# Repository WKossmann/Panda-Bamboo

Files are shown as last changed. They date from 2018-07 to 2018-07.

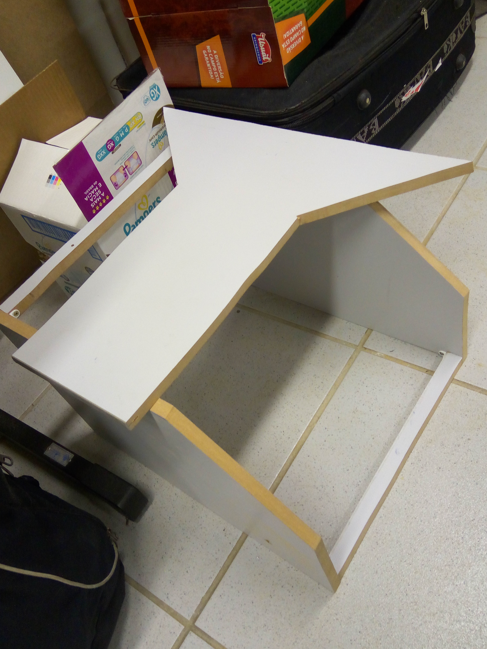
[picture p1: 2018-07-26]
IMG_20170504_185952.jpg

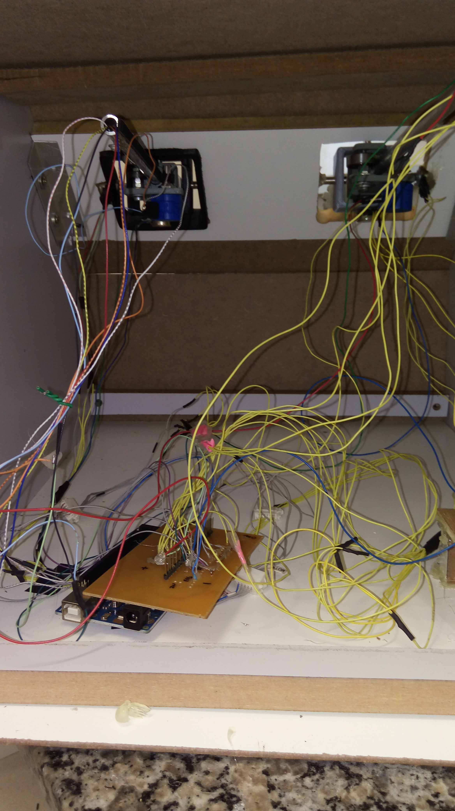
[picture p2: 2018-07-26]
20170629_162037.jpg

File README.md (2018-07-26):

# Panda-Bamboo
Projeto de um simulador de cirurgia laparoscópica, desenvolvido para a disciplina de Projeto Integrado do curso de Engenharia Mecatrônica da UFRN.
## Autores
- ANDRES ANTONIO ALVARADO ROJAS
- ELITELMA DA SILVA SOUZA DE ARAÚJO
- JOÃO BEZERRA DA ROCHA NETO
- TIAGO HÉRIQUE SILVA DE ALMEIDA
- URURAÍ DE CAMPOS GUIMARÃES FILHO
- WENDELL ALVES DA SILVA
- WILLIAN KOSSMANN DA SILVA

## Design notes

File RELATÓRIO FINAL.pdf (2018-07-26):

UNIVERSIDADE FEDERAL DO RIO GRANDE DO NORTE CENTRO DE TECNOLOGIA
MCA0004 - PROJETO INTEGRADO DE MECATRÔNICA

Docentes:
ADELARDO ADELINO DANTAS DE MEDEIROS PABLO JAVIER ALSINA
SAMAHERNI MORAIS DIAS
MARCIO VALERIO DE ARAUJO

SIMULADOR DE CIRURGIA LAPAROSCÓPICA DE BAIXO CUSTO

Discentes:
ANDRES ANTONIO ALVARADO ROJAS ELITELMA DA SILVA SOUZA DE ARAÚJO JOÃO BEZERRA DA ROCHA NETO TIAGO HÉRIQUE SILVA DE ALMEIDA URURAÍ DE CAMPOS GUIMARÃES FILHO WENDELL ALVES DA SILVA
WILLIAN KOSSMANN DA SILVA

Natal-RN

2017

ANDRES ANTONIO ALVARADO ROJAS: 20160153730

ELITELMA DA SILVA SOUZA DE ARAÚJO: 20160153777

JOÃO BEZERRA DA ROCHA NETO: 20160153937

TIAGO HÉRIQUE SILVA DE ALMEIDA: 20160154030

URURAÍ DE CAMPOS GUIMARÃES FILHO: 20160154040

WENDELL ALVES DA SILVA: 20160154059

WILLIAN KOSSMANN DA SILVA: 20160154068

### SIMULADOR DE CIRURGIA LAPAROSCÓPICA DE BAIXO CUSTO

Relatório Final apresentado à disciplina de Projeto
Integrado | de | Mecatrônica, | correspondente | à
avaliação da 3ª unidade do semestre 2017.1 do curso de Engenharia Mecatrônica da Universidade Federal do Rio Grande do Norte, sob orientação dos Professores Adelardo Adelino Dantas de Medeiros, Pablo Javier Alsina, Samaherni Morais Dias e Márcio Valério de Araújo.

Natal-RN
2017

Resumo

Este relatório descreve a construção de um Simulador de Cirurgia Laparoscópica de

Baixo custo, desenvolvido para o componente curricular MCA-0004 Projeto Integrado de

Mecatrônica, do curso de Engenharia Mecatrônica da Universidade Federal do Rio Grande do

Norte (UFRN).

LISTA DE FIGURAS

Figura 1: Corpo da ferramenta em software CAD | 09
Figura 2: Ferramenta montada | 10
Figura 3: Potenciometro linear | 11
Figura 4: Mecanismo Pinhão cremalheira | 11
Figura 5: Potenciometro multi voltas | 12
Figura 6: Haste com cremalheira | 12
Figura 7: Encoder ky-040 | 13
Figura 8: Arduino Mega | 13
Figura 9: Circuito feito em software Eagle® | 14
Figura 10: Fundo do software criado no Autodesk Maya | 15
Figura 11: Haste da ferramenta feita no Autodesk Maya | 15
Figura 12: Ponta da ferramenta feita no Autodesk Maya | 16
Figura 13: Imagem do simulador | 16
Figura 14: Configurações de Interface feitas pelo usuário | 17

SUMÁRIO

1. INTRODUÇÃO (https://docs.google.com/document/d/1a3AnUuqHgW0-QvIK-lkkv6T01XCh_yttxYC3SoFElAQ/edit) | 6
2. (https://docs.google.com/document/d/1a3AnUuqHgW0-QvIK-lkkv6T01XCh_yttxYC3SoFElAQ/edit) OBJETIVO | 7
3. MATERIAIS (https://docs.google.com/document/d/1a3AnUuqHgW0-QvIK-lkkv6T01XCh_yttxYC3SoFElAQ/edit) E MÉTODOS | 8
3.1. (https://docs.google.com/document/d/1a3AnUuqHgW0-QvIK-lkkv6T01XCh_yttxYC3SoFElAQ/edit) PROJETO MECÂNICO | 8
3.1.1 MESA DE TRABALHO | 8
3.1.2 FERRAMENTAS | 9
3.2. (https://docs.google.com/document/d/1a3AnUuqHgW0-QvIK-lkkv6T01XCh_yttxYC3SoFElAQ/edit) PROJETO ELETRÔNICO | 10
3.3 (https://docs.google.com/document/d/1a3AnUuqHgW0-QvIK-lkkv6T01XCh_yttxYC3SoFElAQ/edit) ARQUITETURA DE SOFTWARE | 14
3.3.1 TASKS E SAÍDA DA SIMULAÇÃO | 19
3.3.2 ARQUIVO DE CONFIGURAÇÕES DO PANDA 3D | 19
4. ORÇAMENTO | 20
5. CONCLUSÃO (https://docs.google.com/document/d/1a3AnUuqHgW0-QvIK-lkkv6T01XCh_yttxYC3SoFElAQ/edit) | 21
6. REFERÊNCIAS (https://docs.google.com/document/d/1a3AnUuqHgW0-QvIK-lkkv6T01XCh_yttxYC3SoFElAQ/edit) | 22
7. (https://docs.google.com/document/d/1a3AnUuqHgW0-QvIK-lkkv6T01XCh_yttxYC3SoFElAQ/edit) ANEXOS | 2

### 1. Introdução

É indiscutível que a evolução tecnológica favoreceu o avanço na medicina, podemos

usar como exemplo clássico a laparoscopia surgida em torno de 1902, a princípio para

procedimentos ginecológicos, porém foi mostrando-se muito eficaz então mais tarde em meados

dos anos 80 deu-se início a um novo conceito cirúrgico, a cirurgia laparoscópica, menos

grosseira e invasiva, ela foi responsável por diminuir o tempo de recuperação e a dor causada

pela cirurgia convencional, por isso difundiu-se tão rapidamente.

Através dessa técnica é possível acessar quase todos os órgãos com aparelhos contendo

ferramentas cirúrgicas, os quais permitem a interação do médico com o corpo do paciente por

meio de uma pequena incisão na região a ser tratada com o uso de um laparoscópio que permite

visualizar e tratar a região desejada.

Por apresentar diversas vantagens, este procedimento tornou-se altamente requisitado,

entretanto a dificuldade em capacitar profissionais neste tipo de procedimento faz com que o

mesmo apresente uma curva de aprendizado muito lenta, isto se deve ao fato dos estudantes de

medicina não terem muitas possibilidades de aulas práticas neste tipo de cirurgia. Existem

estudos que constatam que os médicos necessitam de 20 a 70 cirurgias para adquirirem

habilidade com esse procedimento, e com isso, diminuir o tempo de cirurgia.
É comum a existência de produtos biomédicos no mercado nacional, dentre eles alguns

simuladores de cirurgia laparoscópica com os mais diferentes tipos de tecnologia e abordagens,

uns são meras caixas de treinamento simples e já outros dispõem da mais alta tecnologia de

hardware e software, o custo desses equipamentos aumentam de acordo com a tecnologia

envolvida e o alto valor agregado a esses produtos é um dos limitantes ao seu acesso.

Tendo em vista a necessidade de equipamentos deste tipo e pretendendo diminuir

consideravelmente o valor de mercado dos simuladores existentes no mercado, desenvolvemos

um simulador que alie hardware e software em um mesmo produto que dará oportunidade de

aquisição a instituições de ensino, para que seus residentes possam treinar cirurgias desse tipo e

com isso, diminuir a curva de aprendizado.

### 2. Objetivo

Este trabalho tem como objetivo desenvolver um simulador de cirurgia laparoscópica de

baixo custo e com interface gráfica amigável para seus usuários com o propósito de treinar

estudantes de medicina.

### 3. Materiais e Métodos

O simulador de cirurgia laparoscópica proposto é subdividido em três módulos, sendo

eles: o projeto mecânico e o projeto eletrônico,onde ambos configuram a parte de hardware e um

software com interface amigável capaz de reproduzir os movimentos feitos nas ferramentas do

simulador no computador.

### 3.1 Projeto Mecânico

O projeto mecânico do simulador consiste em uma mesa de trabalho e duas ferramentas.

### 3.1.1 Mesa de trabalho

A mesa de trabalho é a região que simula o abdômen do corpo humano. Feita em sua

maior parte de madeira, é responsável por abrigar o microcontrolador e alguns sensores para

capturar os movimentos provenientes da ferramenta, além de ser a base do simulador devendo

ser posicionada em cima de uma mesa ou balcão.

Sua estrutura é em formato de uma caixa retangular, com um chanfro grande em uma de

suas arestas. As paredes laterais foi feita com uma chapa de “madeira grossa” única fixadas uma

na outra com pequenas hastes de “madeira grossa”, para proporcionar resistência a estrutura. Na

região do chanfro há também uma chapa, com dois furos quadrados grandes, onde se localizará o

conjunto de sensores de captura dos movimentos angulares e movimento linear de profundidade.

A parte superior da caixa tem como objetivo ser suporte para um notebook ou monitor para a

visualizar a virtualização da simulação. As regiões que ficaram expostas foram cobertas com

folhas de “madeira fina” para não ficar uma estrutura muito pesada e ao mesmo tempo

proporcionar proteção aos componentes internos do simulador.

Para a captura dos movimentos angulares, foi fixado um potenciômetro em uma das

paredes dos furos e acoplado a ele há uma peça quadrada interna que possui um grau de

movimento angular. Outro potenciômetro está fixado nesta peça a qual está acoplado uma

segunda peça interna que possui outro grau do movimento angular rotacionado à 90º do anterior

para assim ser possível a medição dos ângulos de rotação. Na peça central há um furo por onde

passa a haste da ferramenta e em sua ponta do lado interno da caixa está localizado o

potenciômetro multivoltas que, em conjunto da cremalheira presente na haste da ferramenta,

captura o movimento linear de entrada e saída da haste da ferramenta.

### 3.1.2 Ferramentas

Construímos o corpo das ferramentas com prototipagem rápida, impressa em ABS e PLA

a partir de um modelo em 3D criado com software CAD. Nelas estão dispostas duas cavidades

onde sensores foram posicionados e uma região semi-aberta onde ficará a roleta de giro para

simular o giro da haste. Há também superfícies auxiliares para ajudar na fixação dos sensores e

dutos por onde os fios de alimentação e de sinais passarão até chegar a eles.

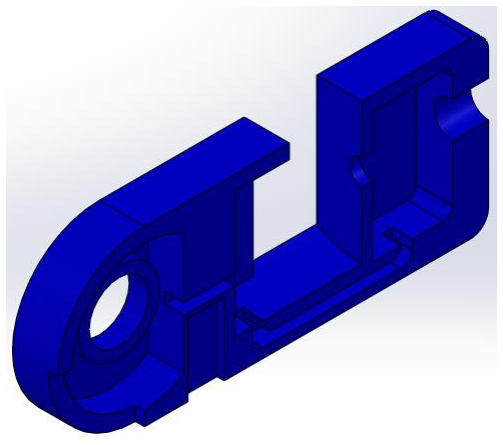
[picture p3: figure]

Figura 1 - Corpo da ferramenta em software CAD

Fonte: Foto elaborada pelo autor

Para ficar o mais parecido possível com a forma de manuseio de uma ferramenta

laparoscópica real utilizamos a estrutura de uma tesoura comercial. Esta tesoura foi dividida e

removida parte de sua lâmina, uma parte da tesoura é fixada a ferramenta, e a outra é fixada a um

potenciômetro na parte posterior da ferramenta, dando uma liberdade de movimento semelhante

a da ferramenta original.

Na parte frontal da ferramenta há uma abertura circular, por onde passa a haste da

ferramenta e é fixada a um potenciômetro que captura o giro desta haste. A haste tem a função de

transferir os movimentos angulares e de profundidade realizados para os sensores dispostos na

mesa de trabalho, juntamente com os fios de alimentação e sinais dos sensores contidos na

ferramenta.

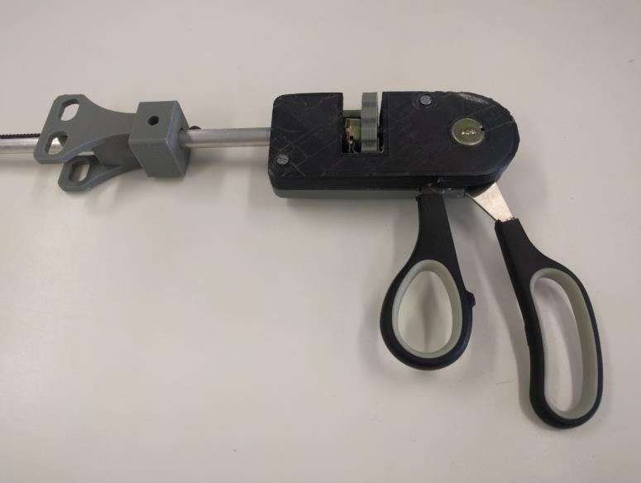
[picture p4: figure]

Figura 2 - Ferramenta montada

Fonte: Foto elaborada pelo autor

### 3.2 Projeto Eletrônico

Este equipamento dispõe de uma eletrônica embarcada, tanto na mesa de trabalho quanto

nas ferramentas que serão operadas pelos usuários. Tratam-se de sensores dispostos de maneiras

estratégicas e conectados a um microcontrolador a fim de capturar todos os movimentos

realizados nas ferramentas para serem reproduzidos no computador.

Nos furos dispostos na mesa de trabalho foram acoplados dois potenciômetros lineares

simples em cada furo, com resistência de 1kΩ e dimensão de 16,5 x 29 x 7,3 mm, com a

finalidade de medir os movimentos das ferramentas em relação aos eixos ‘x’ e ‘y’. Outro

potenciômetro desse tipo foi colocado na junta de rotação da tesoura, e a variação da sua

resistência irá determinar se a ponta da ferramenta está aberta ou fechada. Um quarto

potênciometro também foi colocado no final da empunhadura, e teve seu eixo conectado a haste,

este é responsável pela junção da mesma com a ferramenta, logo sua rotação é também a rotação

da haste. A figura 3 mostra os potenciômetros usados.

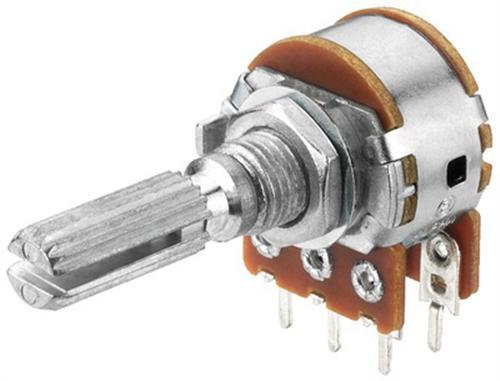
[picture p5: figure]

Figura 3: Potenciômetro linear

Disponível em : http://www.adaline.co.th/product/303/vr-potentiometer-100k

Acesso em 28 de jun. 2017

Para o movimento de translação da ferramenta, ou seja, o movimento da mesma em

relação ao eixo ‘z’, elaboramos um mecanismo do tipo pinhão cremalheira, Como mostra a

figura 4.

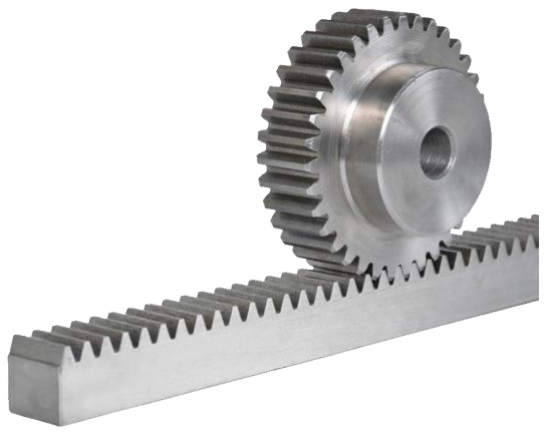
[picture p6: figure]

Figura 4: Mecanismo Pinhão cremalheira

Disponível em: http://www.automotion.com.br/produtos/cremalheiras-e-pinhoes/dente-reto

Acesso em 28 de jun. 2017

Uma engrenagem foi fixada ao eixo de um potenciômetro do tipo multi voltas com 10

voltas, resistência de 10kΩ e dimensão de 9 x 7,94 mm, e na haste foi fixada uma cremalheira

que será encarregada de girar o pinhão e consequentemente girar o potenciômetro, e sua variação

será equivalente ao movimento de translação da haste. Abaixo podemos ver o potenciômetro

usado e a cremalheira.

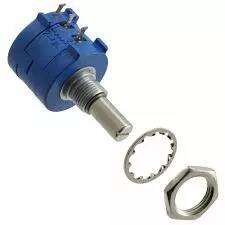
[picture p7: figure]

Figura 5: Potenciômetro multi voltas

Disponível em:

/eletronicos.mercadolivre.com.br/pecas-componentes-eletricos-potenciometros/potenciometro-10k-multivoltas

Acesso em 28 de jun. 2017

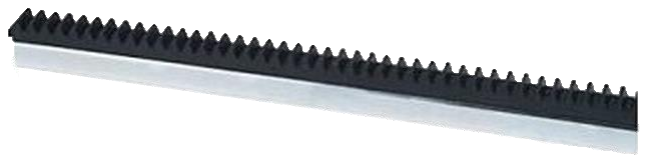
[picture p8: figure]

Figura 6: Haste com cremalheira

Disponível em : http://lista.mercadolivre.com.br/barra-de-cremalheira-avulsa-port%C3%A3o-goiania

Acesso em 28 de jun. 2017

A empunhadura ainda dispõe de mais um sensor do tipo encoder ky-040 com resolução

de 20 pulsos, tensão de operação de 5v e dimensão de 32 x 19 x 30 mm, responsável também

pela rotação da haste da ferramenta, sua função é redundante junto ao quarto potenciômetro

linear, entretanto seu acionamento é feito de maneira diferente, visto que, este encoder será

acoplado a roleta de giro e quando a mesma for acionada ele emitirá pulsos que indicarão o

sentido da rotação da ferramenta.

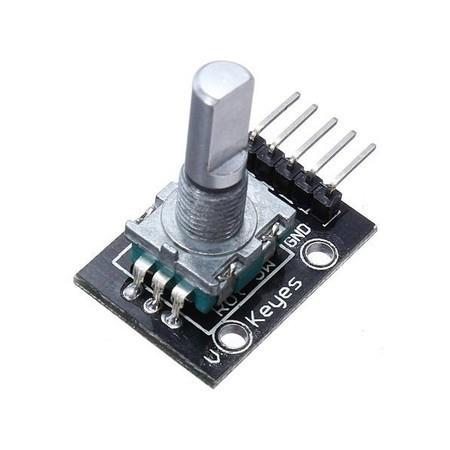
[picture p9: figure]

Figura 7: Encoder Ky-040

Disponível em: http://lista.mercadolivre.com.br/barra-de-cremalheira-avulsa-port%C3%A3o-goiania

Acesso em 18 de jun. 2017

Com todos os sensores dispostos nas ferramentas e na mesa de trabalho, é necessário

agora a comunicação dos mesmos com o computador, para tal fim, é essencial o uso de um

microcontrolador responsável pela aquisição desses sinais. Para este projeto optamos pelo

Atmega2560 embarcado na placa de desenvolvimento Arduíno® , pois o mesmo possui 16

canais de entradas analógicas e também saída de comunicação serial com interface USB

(Universal Serial Bus) capaz de fazer a transmissão destes dados colhidos para o computador.

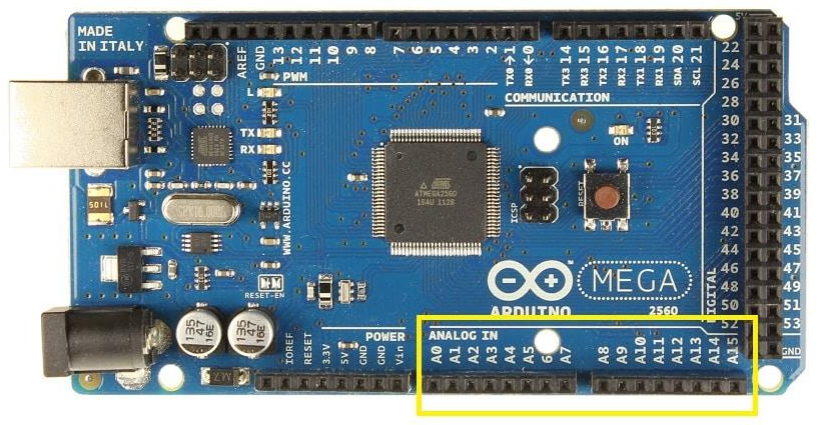
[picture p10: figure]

Figura 8: Arduíno Mega destacando os canais analógicos utilizados

Disponível em: https://www.embarcados.com.br/arduino-mega-2560/

Acesso em 28 de jun. 2017

Com o intuito de fazer a ligação de todos os sensores embarcados com o

microcontrolador foi projetado um circuito em software Eagle® para ser acoplado ao arduino em suas devidas entradas analógicas, com isso, ele fará a leitura de todos os sensores e em

seguida encapsulará estes dados para serem enviados ao computador. A figura 9 mostra o

esquemático do circuito feito.

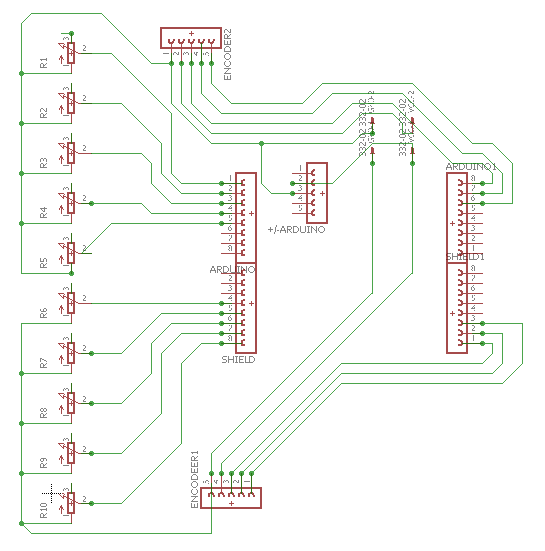
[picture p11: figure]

Figura 9: Circuito feito em software Eagle®

Fonte: Elaborada pelo autor.

### 3.3 Arquitetura de Software

A interface gráfica configura o módulo de software, ou seja, é o ambiente de trabalho

onde as ferramentas serão projetadas virtualmente reproduzindo os movimentos feitos pelas

ferramentas físicas dispostas na mesa de trabalho. Para o desenvolvimento deste sistema foram

utilizados: a linguagem Python® e o Panda 3D.

O Panda 3D é um motor que dispõe de sub rotinas capazes de renderizar objetos 3D, ele

está bastante difundido no ramo da animação e em desenvolvimentos de jogos, é open-source e

livre para qualquer propósito, por isso, podemos utilizá-lo sem nenhum tipo de licença.

Como citado acima, o Panda 3D é responsável pelas transformações lineares de objetos

em 3D, mas a criação dos mesmos deve feita em outro software, para isso escolhemos o software

chamado Autodesk Maya. Este programa permite fazer a modelagem em 3D de objetos e

também é muito utilizado nas indústrias de animação e games.

Os modelos criados no Autodesk Maya para a simulação foram:

- Fundo: Caixa com chão, paredes laterais e parede frontal, e textura de órgãos internos,

figura 10.

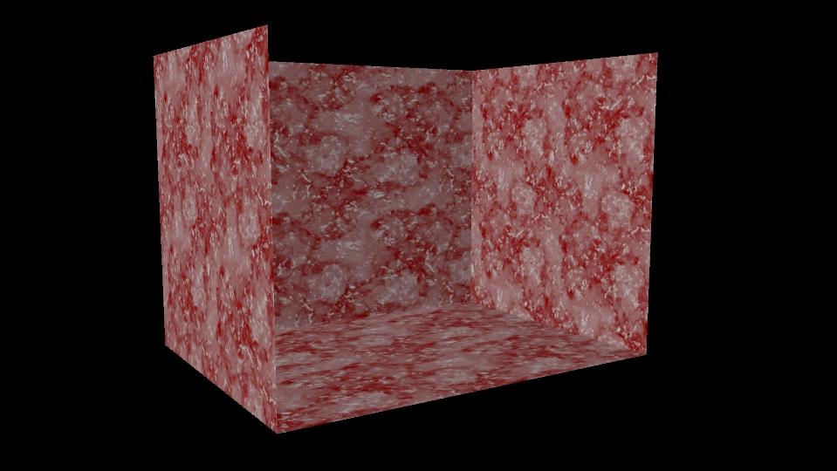
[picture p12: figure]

Figura 10: Fundo do software criado no Autodesk Maya

Fonte: Elaborada pelo autor.
- Junta: Simula o ponto de rotação para as hastes, é uma esfera transparente, logo não pode

ser visualizada na simulação.

- Haste: Uma haste como filha de cada junta, é apenas um cilindro com textura metálica,

figura 11.

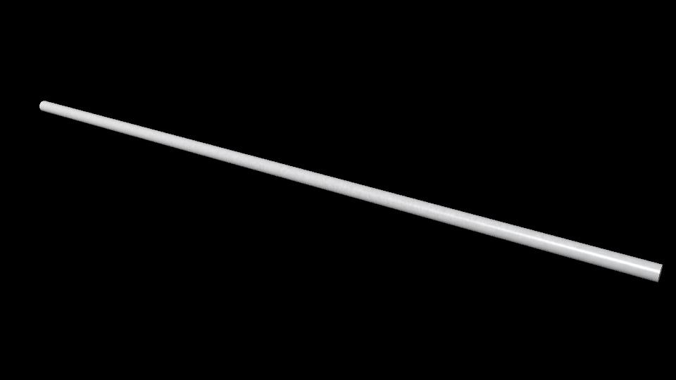
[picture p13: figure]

Figura 11: Haste da ferramenta feita software criado no Autodesk Maya

Fonte: Elaborada pelo autor.
- Tesoura: o modelo é apenas metade da tesoura com textura metálica, assim, cada haste

tem dois modelos de tesoura, virados um para o outro, como filhos. O centro de rotação

de cada metade se encontra na ponta da haste, figura 12.

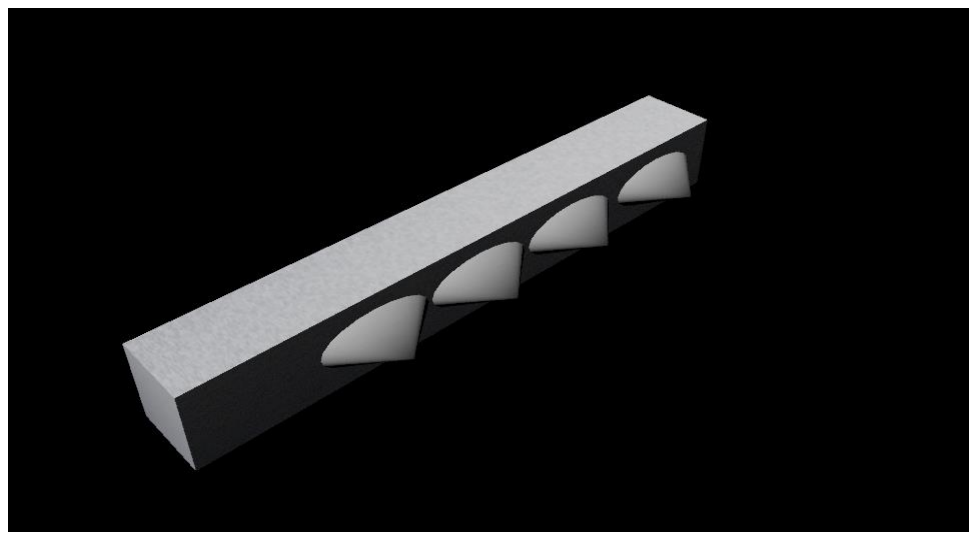
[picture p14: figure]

Figura 12: Ponta da ferramenta feita software criado no Autodesk Maya

Fonte: Elaborada pelo autor.
Os movimentos utilizados nos modelos são de rotação e translação das hastes em relação

à junta, e a de abrir e fechar as tesouras de cada haste.

De posse dos objetos modelados, o Panda 3D fica responsável por reunir todos esses

objetos em um mesmo ambiente gráfico, além de obedecer a um script onde ele atualiza as

imagens em tempo real e também se comunica externamente via serial com o microcontrolador e

tudo isso sem perder desempenho, isto é, com um número considerável de frames por segundo.

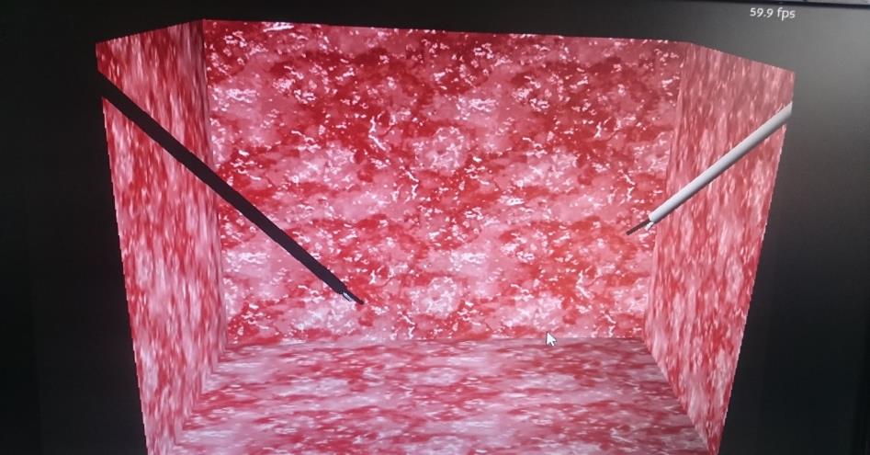
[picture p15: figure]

Figura 13: Imagem do simulador

Fonte: Elaborada pelo autor.
A iluminação é feita com duas fontes de luz: uma ambiente bem fraca, que tem como

propósito suavizar as sombras e não deixá-las em preto sólido; e uma focal, localizada junto à

câmera, esta, ao se movimentar cria sombras dos objetos sobre o fundo, dependendo das

distâncias.

Existem dois tipos de câmera disponíveis para serem utilizados na simulação, escolhido

na GUI de Opções:

- Câmera-Ferramenta: A câmera é localizada na ponta da haste escolhida, e a tesoura é

escondida, dessa forma tem-se a visão no referencial da ponta da haste, e ao ser colocada

como filha da haste, todo movimento feito na haste é repassado à câmara. Neste modo, o

mouse é desabilitado para controle da câmera.

- Câmera-Virtual: A câmera é colocada na posição default da simulação e a sua

movimentação é feita utilizando o mouse (botão esquerdo é translação no plano XZ,

botão direito permite translação no eixo Y e o botão central rotaciona a câmera nos seus

próprios eixos). Neste modo, as duas ferramentas possuem tesoura, a diferença do

primeiro modo onde a ferramenta que tem a câmera não possui tesoura visível. Como

mostra a figura 14.

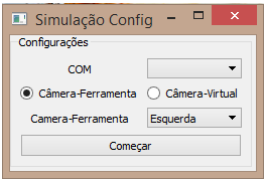
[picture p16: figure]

Figura 14: Configurações da Interface do usuário

Fonte: Elaborada pelo autor.

Ao rodar o programa, a primeira que coisa que será carregada será uma GUI de

configuração, contendo as seguintes opções:

- Escolher a porta onde será feita a comunicação (só serão listadas as portas onde pode ser

feita a comunicação) [ComboBox].

- Escolher entre utilizar Câmera-Ferramenta ou Câmera-Virtual (explicado no tópico de

Simulação) [RadioBox].

- Escolher qual ferramenta será utilizada como a câmera (no caso da Câmera-Ferramenta)

[ComboBox].

Depois de salvar estas configurações, a interface estará pronta para o uso e o usuário poderá manipular as ferramentas da maneira que desejar acompanhando-as na tela do seu

monitor em tempo real.

O software fará requisições de dados ao arduino que enviará uma String via serial, essa

String será processada pelo programa escrito em Python® e em seguida determinará as posições

e orientações das ferramentas. A String de dados enviados pelo arduino terá o seguinte formato:

“F<phi_e>G< gama_e>T<theta_e>D<dist_e>R<roda_e>G<gatilho_e>

f<phi_d>g< gama_d>t<theta_d>d<dist_d>r<roda_d>g<gatilho_d>”*[soma]”

Onde a [soma] é a soma de todos os caracteres da string de dados. No caso da soma

vindo na string não bater com a soma feita do lado do computador, a string é descartada e os

valores não são atualizados. O mesmo acontecerá no caso de algum dos caracteres

correspondentes aparecer fora de ordem, ou ser algum outro caractere não especificado.

No Arduino, os dados vindos dos sensores são lidos em alta frequência, mas a String só é

formada e enviada quando há uma requisição de dados por parte do computador principal. No

simulador, foi criado um arquivo python com a finalidade de Driver entre o Arduino e a

Simulação. Nele existem funções para inicializar a comunicação com a porta serial escolhida na

GUI de opções, fazer a requisição de dados e pegar as informações referentes a cada haste por

separado.

### 3.3.1 Tasks e Saída da Simulação

Tasks no Panda3D são sub rotinas que são acionadas a cada certo intervalo de tempo. Na

simulação há uma task que age a cada 20ms, que faz a requisição de dados por parte do Arduino

e atualiza os valores das transformações das duas ferramentas. Este intervalo de tempo não

interfere com o fps da simulação [mais detalhes em Arquivo de Configurações do Panda3D].

Para sair da simulação, existe uma ligação com a tecla ESC do teclado para finalizar a

simulação e o programa como um todo.

### 3.3.1 Arquivo de Configurações do Panda3D

Um arquivo de configurações foi criado que refere a certos parâmetros utilizados pelo

Panda3D para como a simulação deve ser criada.

Alguns dos parâmetros modificados foram:

- Ao começar a simulação colocar ela em fullscreen.
- Mostrar o fps no canto superior direito da tela da simulação.
- [Default] O simulador tenta manter o fps numa frequência que seja boa para o monitor

onde esteja sendo apresentada (no caso dos nossos notebooks foi constatado 60.0 fps)

### 4. Orçamento

Os custos do projeto são demonstrados segundo a tabela abaixo:

QTD | Descrição | Preço (UN) | Preço Total | Frete
10,00 | Potenciômetros Simples | R$ 2,00 | R$ 20,00 | Não
2,00 | Potenciômetros Multivoltas (10 Voltas) | R$ 16,50 | R$ 33,00 | Sim
2,00 | Encoders | R$ 12,00 | R$ 24,00 | Sim
1,00 | Fonte 5V | R$ 25,00 | R$ 25,00 | Não
1,00 | Estrutura de Madeira | R$ 120,00 | R$ 120,00 | Não
2,00 | Tesoura simples | R$ 3,50 | R$ 7,00 | Não
2,00 | Pistolas (Impressão 3D) | R$ 35,00 | R$ 70,00 | Não
2,00 | Rodinha para o movimento da Haste | R$ 10,00 | R$ 20,00 | Não
1,00 | Componentes Impressos | R$ 20,00 | R$ 20,00 | Não
1,00 | Arduino Mega | R$ 0,00 | R$ 0,00 | Não
1,00 | Cola | R$ 5,00 | R$ 5,00 | Não
1,00 | Componentes para PCB | R$ 30,00 | R$ 30,00 | Não
Total Orçamentado | R$ 374,00 | Frete Total | R$ 21,90
Total Gasto | R$ 147,90

### 5. Conclusão

Levando-se em consideração a necessidade de treinamento dos residentes de medicina

neste tipo de procedimento, é imprescindível o uso de simuladores de cirurgia laparoscópica na

formação desses futuros médicos, entretanto, o alto custo envolvido nesses tipos de

equipamentos que abrange hardware e software existentes no mercado, dificulta a aquisição

destes produtos. Percebemos que a da construção de um simulador de cirurgia laparoscópica de

baixo custo, traz ao mercado uma opção intermediária e mais tangível, por se tratar de um

produto fabricado com equipamentos nacionais e totalmente comercializados no país.

### 6. Referências

SZEGÖ, | T. | A | Inovação | da | Cirurgia | Laparoscópica

<http://www.sbcbm.org.br/wordpress/a-inovacao-da-cirurgia-laparoscopi> Acesso em 28

de junho de 2017;

FERRAZ, E. D.; LACOMBE, D. Estado Atual da Cirurgia Híbrida Colo-Retal

<http://www.sobracil.org.br/revista/rv010101/artigo05.htm> Acesso em 28 de junho de

2017;

Manual Panda3D <https://www.panda3d.org/> Acesso em 28 de junho de 2017;

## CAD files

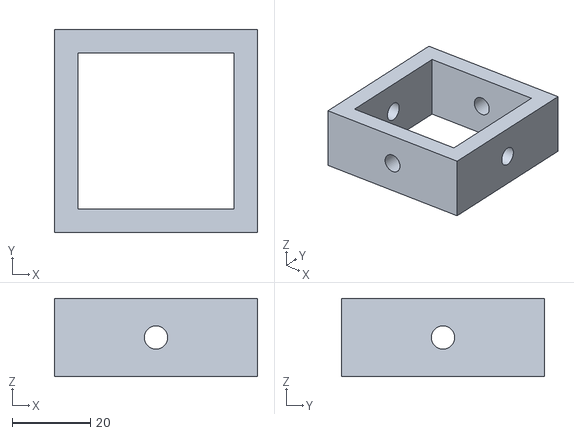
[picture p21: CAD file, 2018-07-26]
Projeto Mecânico/Anel Meio.STL
52.0 x 52.0 x 20.0

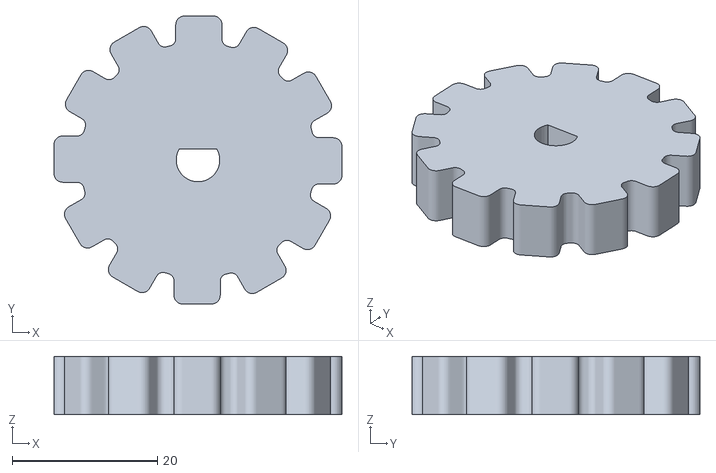
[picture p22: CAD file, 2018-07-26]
Projeto Mecânico/Roda Ferramenta.STL
39.7 x 39.7 x 8.00

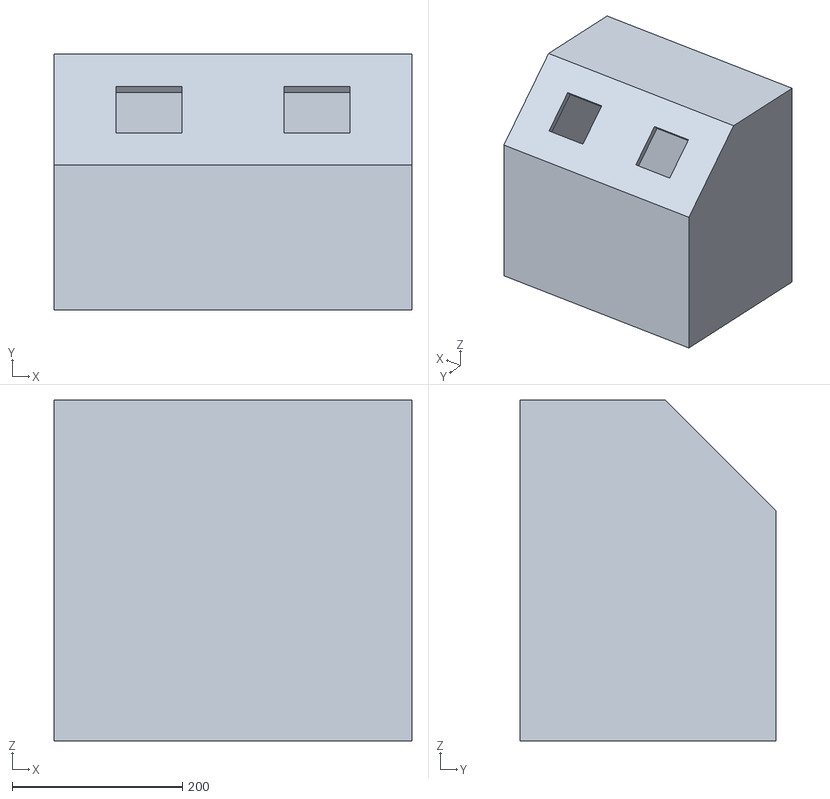
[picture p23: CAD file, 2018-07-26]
Projeto Mecânico/Caixa.STL
420.0 x 300.0 x 400.0

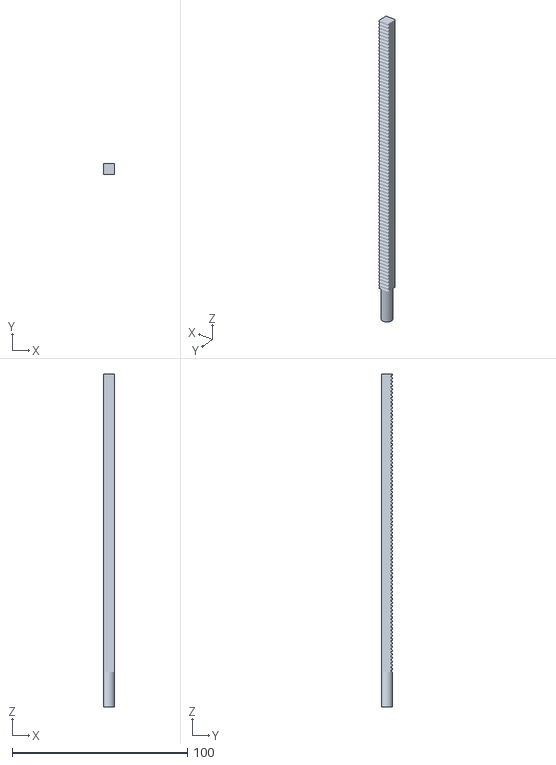
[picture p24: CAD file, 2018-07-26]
Projeto Mecânico/Cremalheira.STL
6.40 x 6.40 x 190.0

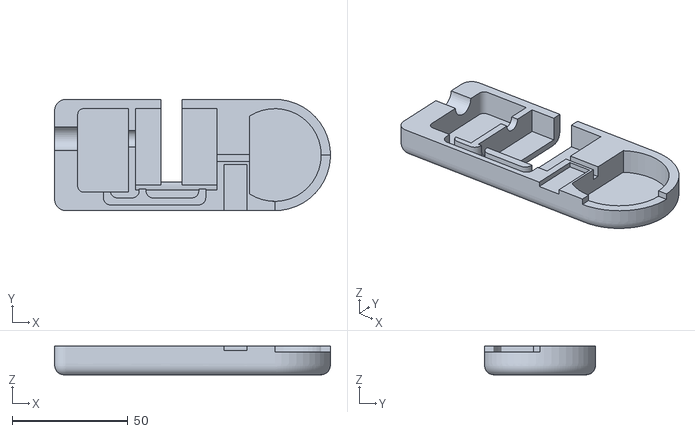
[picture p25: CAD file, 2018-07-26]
Projeto Mecânico/Ferramenta Lado Direito.STL
119.0 x 48.0 x 12.5

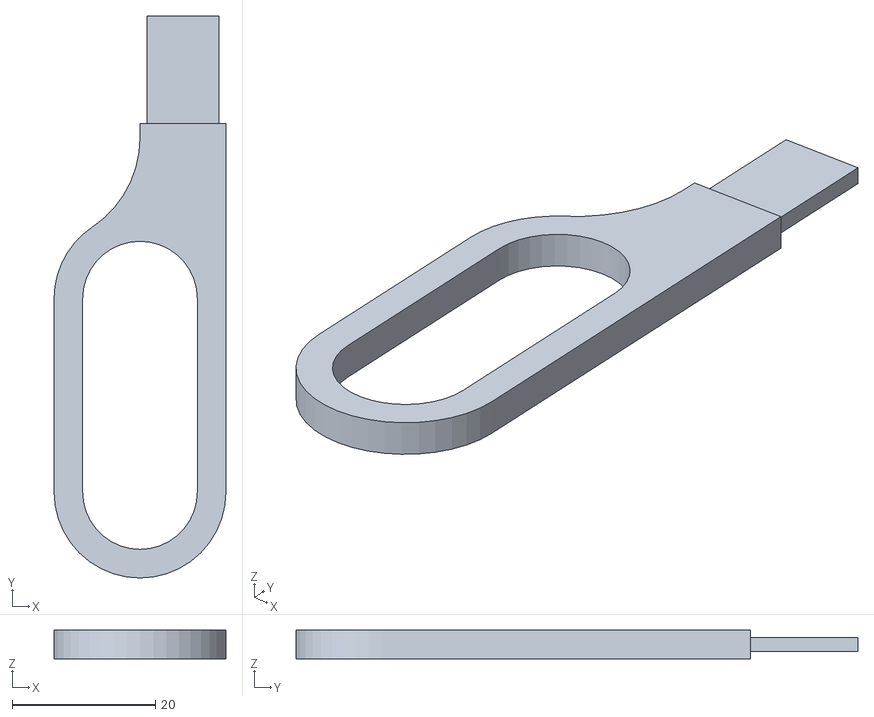
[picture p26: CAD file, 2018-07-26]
Projeto Mecânico/Cabo Ferramenta Fixo.STL
24.0 x 78.4 x 4.00

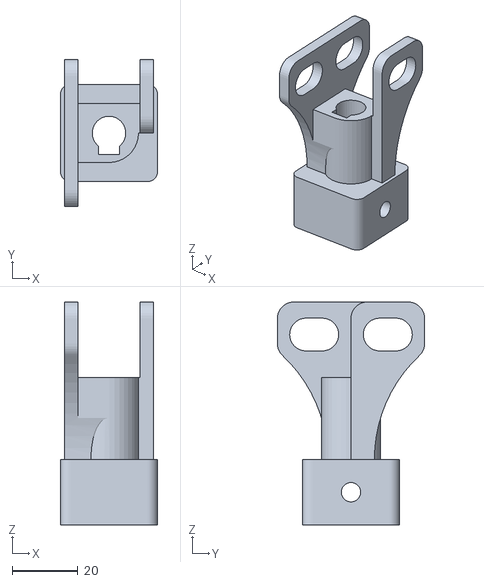
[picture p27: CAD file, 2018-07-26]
Projeto Mecânico/Anel Interno (Luva).STL
29.6 x 44.9 x 68.0

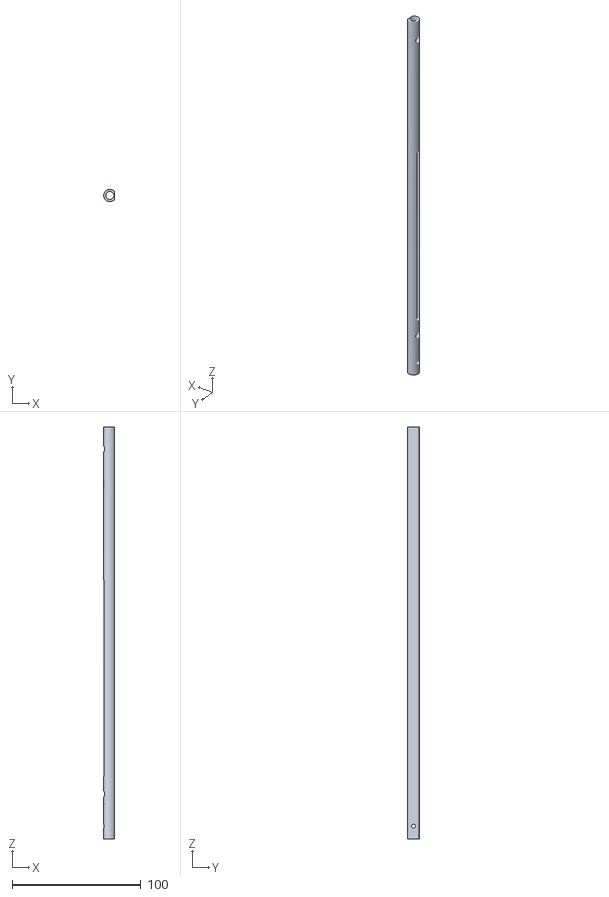
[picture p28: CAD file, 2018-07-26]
Projeto Mecânico/Haste Redonda.STL
8.26 x 9.59 x 320.0

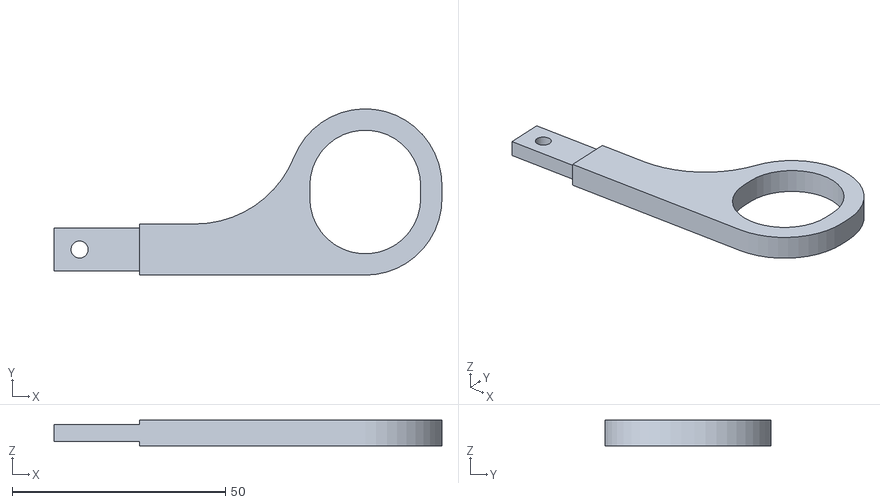
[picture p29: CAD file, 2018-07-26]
Projeto Mecânico/Cabo Ferramenta Movel.STL
91.0 x 39.0 x 6.00

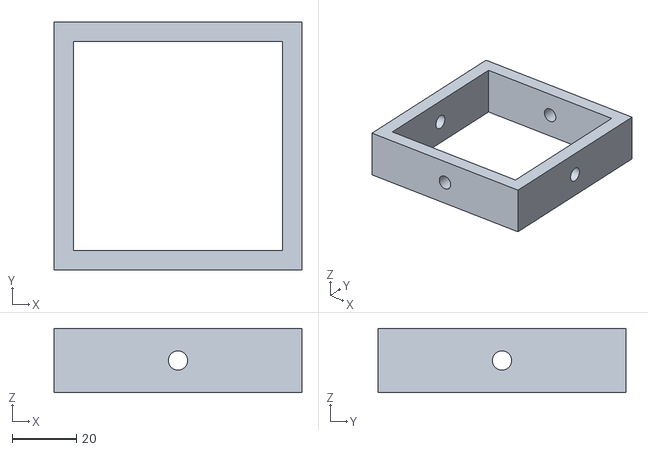
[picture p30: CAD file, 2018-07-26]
Projeto Mecânico/Anel Externo.STL
77.0 x 77.0 x 20.0

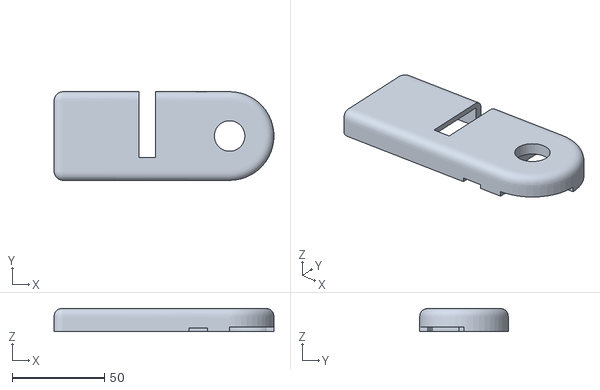
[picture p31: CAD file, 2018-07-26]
Projeto Mecânico/Ferramenta Lado Esquerdo.STL
119.0 x 48.0 x 12.5

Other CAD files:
Projeto Software/PI_PANDA/untitled.blend

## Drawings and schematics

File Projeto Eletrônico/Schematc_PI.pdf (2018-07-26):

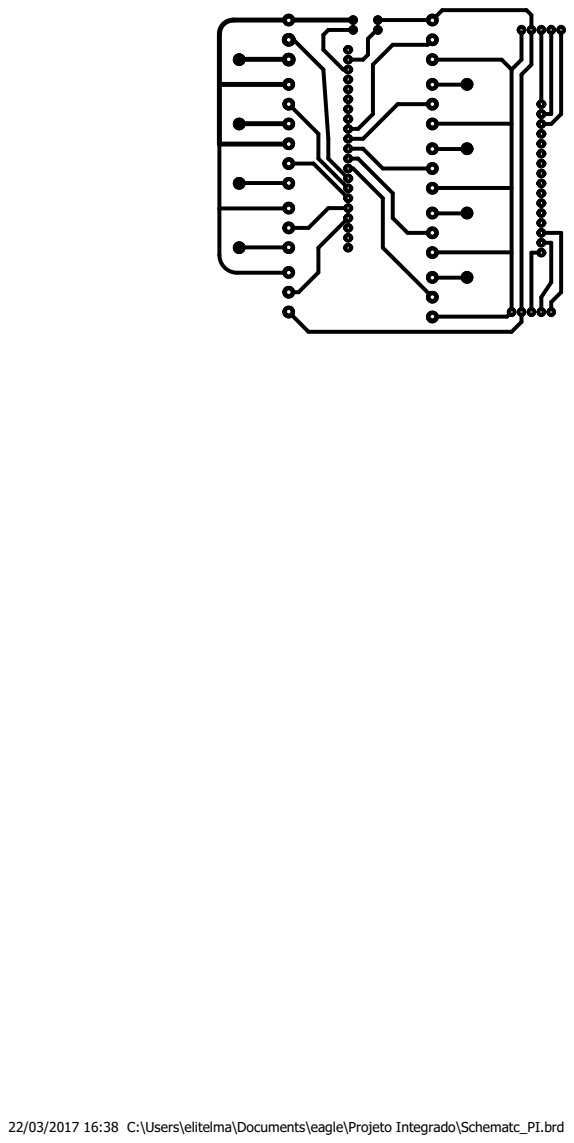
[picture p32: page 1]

22/03/2017 16:38 C:\Users\elitelma\Documents\eagle\Projeto Integrado\Schematc_PI.brd

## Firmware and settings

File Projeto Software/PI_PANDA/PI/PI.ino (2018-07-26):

#include <RotaryEncoder.h>

RotaryEncoder encoder_e(A0, A1);
RotaryEncoder encoder_d(A2, A3);
int pos_nova = 0;
int k = 0;
bool up = 1;
String s;
int sum = 0;
void setup() {
  pinMode(2, INPUT);
  pinMode(3, INPUT);
  pinMode(4, INPUT);
  pinMode(5, INPUT);
  pinMode(6, INPUT);
  pinMode(7, INPUT);
  pinMode(8, INPUT);
  pinMode(9, INPUT);
  pinMode(10, INPUT);
  pinMode(11, INPUT);
  pinMode(12, INPUT);
  pinMode(13, INPUT);
  // put your setup code here, to run once:
  Serial.begin(115200);
}

void loop() {
  // put your main code here, to run repeatedly:
  if (k == 100) up = 0;
  if (k == 1) up = 1;
  //static int pos = 0;
  encoder_e.tick();
  int pos_e = encoder_e.getPosition();
  encoder_d.tick();
  int pos_d = encoder_d.getPosition();
  /*
    if (pos != pos_nova) {
    Serial.print(pos_nova);
    Serial.println();
    pos = pos_nova;
    }
  */
  int a = analogRead(A13);
  int b = analogRead(A12);
  int c = analogRead(A11);
  int d = analogRead(A10);
  int e = analogRead(A9);
  int f = analogRead(A8);
  int g = analogRead(A7);
  int h = analogRead(A6);
  int i = analogRead(A5);
  int j = analogRead(A4);

  sum = 0;
  s = String("F"+String(a)+"_"+"G"+String(b)+"_"+"T"+String(c)+"_"+
              "D"+String(d)+"_"+"R"+String(e)+"_"+"P"+String(f)+"_"+
              "f"+String(g)+"_"+"g"+String(h)+"_"+"t"+String(i)+"_"+
              "d"+String(j)+"_"+"r"+String(pos_e)+"_"+"p"+String(pos_d)+"*");
  for (int j = 0; j < s.length() - 1; j++) sum += int(s.charAt(j));
  s = String(s + String(sum));
  if (Serial.available() > 0) {
    Serial.println(s);
    Serial.read();
  }
  delay(10);
  if (up) k++;
  else k--;
}
